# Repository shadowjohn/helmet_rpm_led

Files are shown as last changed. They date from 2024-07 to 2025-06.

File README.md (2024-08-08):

# helmet_rpm_led
(Arduino D1 mini) 這是一個引擎轉速在拉轉，安全帽上的燈條也在拉轉的故事...

假如我們可以抓到機車的引擎轉速，那就透過無線傳輸把轉速訊號傳到安全帽上顯示

<h3>作者：</h3>
	羽山秋人 (https://3wa.tw)
<br>
<h3>最初開發日期：</h3>
	2024-07-15 23:24
<br>
<h3>版權：</h3>
	MIT License
<br>	
<h3>所需材料：</h3>
<ul>
	<li>1. Arduino D1 mini x 2</li>
	<li>2. RGB Pixel 燈條 5V，間距的話建議 144 ，比較密，長度就自己覺得多長看得爽~</li>
    <li>3. PC817</li>
	<li>4. 基納 (5.1V 1/2w)</li>
	<li>5. 電阻 470Ω 1/2w</li>
	<li>6. 電阻 1KΩ 1/2w</li>
	<li>7. 電阻 1.2KΩ 1/2w</li>
	<li>8. 如果要裝上車，還需要 BUCK DC-to-DC MP1584</li>
    <li>9. 鋰電池 14500 3.7V 800mAh</li>
	<li>10. AA 3號電池 電池盒 單排或雙排</li>
	<li>11. 恥力要很夠</li>
</ul>
<br>
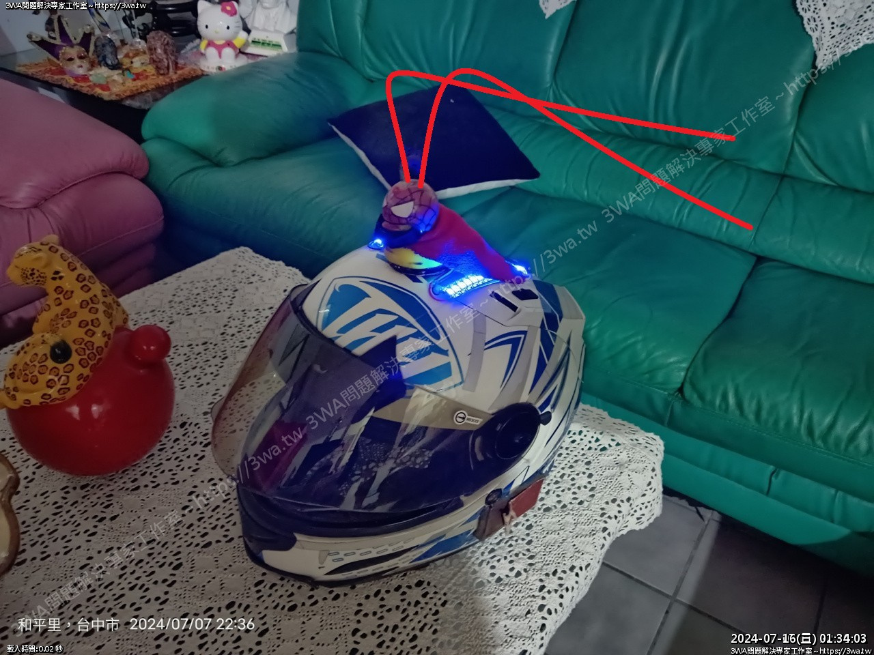
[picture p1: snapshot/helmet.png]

<center>假設那二條像嗄抓的尾巴是 LED 燈條，可以用來顯示車主瘋狂拉轉XD</center>

<br>
使用二塊有 Wifi 的 Arduino D1 mini 作為開發板

<h3>Server端(裝在安全帽上):</h3>
	啟動後會變成 Wifi AP ，等待 Client 端的轉速訊號，只要一收到轉速訊號，就變換燈條的顯示燈數與顏色
	傳輸過程使用 udp 封包
	此分享電路沒有畫出 12V -> 5V 的 Dc-to-DC Buck，可以考慮接個 MP1584 
	另外安全帽如果只用單串 18650 或 14500 ，可能需要用一組 Boost Converter 升壓到 5V 使用
	羽山有空再實驗

<br>
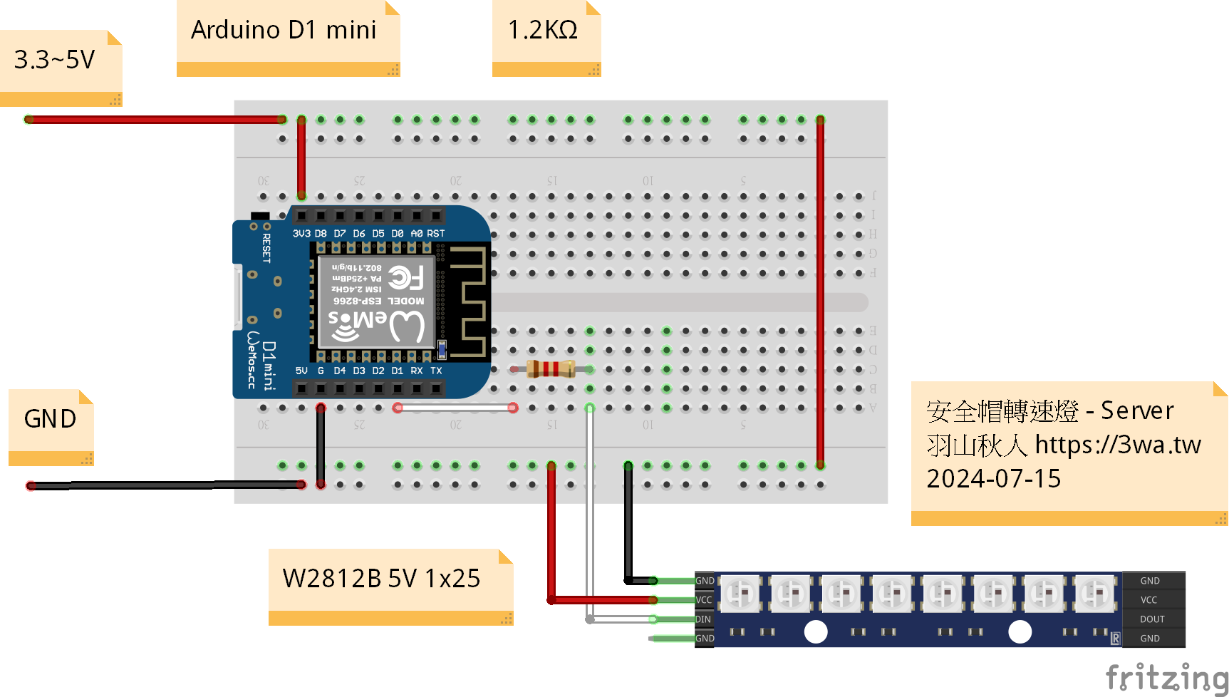
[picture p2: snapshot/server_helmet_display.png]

<center>(Server)安全帽上電路的接線方式</center>

<br>
<br>
<h3>Client端(裝在機車):</h3>
	啟動後會持續偵測引擎轉速，偵測的方式可以接碼表的轉速表訊號線，或是晶式高壓線圈輸入端的黑線或綠線，或是凸台的脈衝訊號線
<br>	
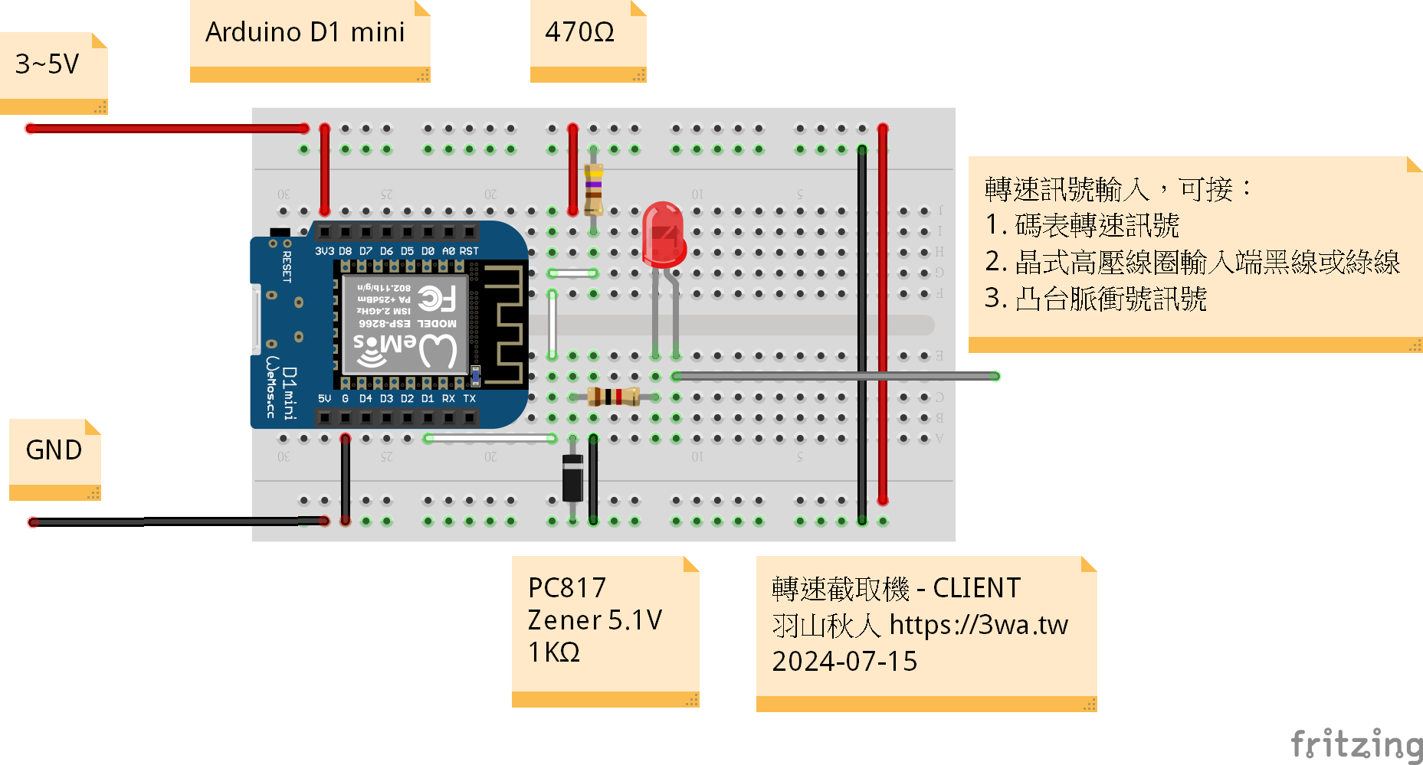
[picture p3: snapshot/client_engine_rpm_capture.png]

<center>(Client)轉速表訊號端的接線方式</center>

<br>
<video autoplay loop style="width:100%; height: auto; position:absolute; z-index: -1;">
  <source src="snapshot/helmet_rpm_led.mp4" type="video/mp4" />  
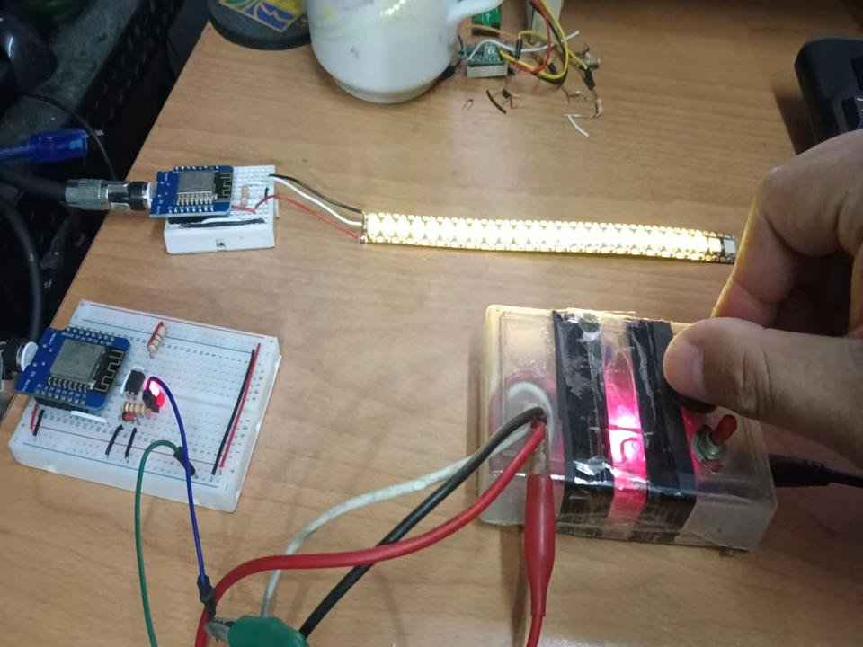
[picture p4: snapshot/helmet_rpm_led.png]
  
</video>
<br>
影片供參考：<a target="_blank" href="https://github.com/shadowjohn/helmet_rpm_led/blob/main/snapshot/helmet_rpm_led.mp4">實作影片</a>

<br><br>
<h3>心得：</h3>
	分享心得：https://3wa.tw/blog/blog.php?id=2091
<br>

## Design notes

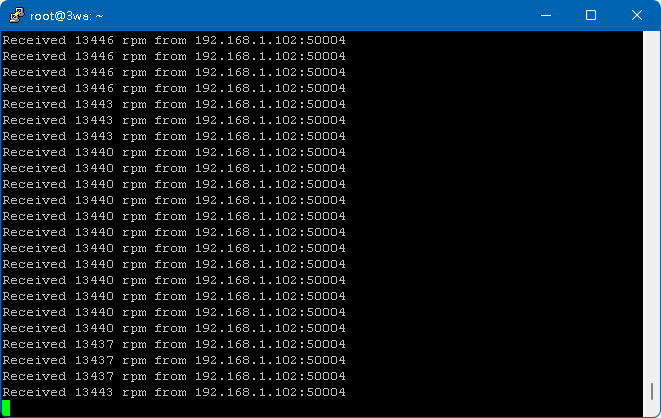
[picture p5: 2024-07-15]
snapshot/s2.png

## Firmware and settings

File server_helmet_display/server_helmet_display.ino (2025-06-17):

/*
 * 伺服端，啟動後會架一組 wifi server，連上的 client 會透過 udp 12345 丟轉速訊號來
 * Author: 羽山 (https://3wa.tw)
 * Author: @FB 田峻墉
 * Release Date: 2024-09-21
 * D1 接至 PC817，為轉速訊號接入端
 */
#include <Arduino.h>
#include <ESP8266WiFi.h>
#include <Adafruit_NeoPixel.h>
#include <WiFiUdp.h>

#define LED_PIN    D1 //接 Pixel LED
#define NUMPIXELS 25 // 25顆 LED
static Adafruit_NeoPixel strip(NUMPIXELS, LED_PIN, NEO_GRB + NEO_KHZ800);

// 收到的 udp 包
static char incomingPacket[255];
// 熱點名稱和密碼
const char* ssid = "3wa_helmet_server";
const char* password = "********";

// 指定熱點的 IP 地址、網關和子網掩碼
IPAddress local_ip(192,168,1,254);
IPAddress gateway(192,168,1,254); // 通常將網關設置為熱點的 IP 地址
IPAddress subnet(255,255,255,0);

// 創建一個 UDP 物件
WiFiUDP udp;
const int udpPort = 12345;


uint32_t blendColors(uint32_t color1, uint32_t color2, int blend) {
  uint8_t r1 = (color1 >> 16) & 0xFF;
  uint8_t g1 = (color1 >> 8) & 0xFF;
  uint8_t b1 = color1 & 0xFF;

  uint8_t r2 = (color2 >> 16) & 0xFF;
  uint8_t g2 = (color2 >> 8) & 0xFF;
  uint8_t b2 = color2 & 0xFF;

  uint8_t r = (r1 * (255 - blend) + r2 * blend) / 255;
  uint8_t g = (g1 * (255 - blend) + g2 * blend) / 255;
  uint8_t b = (b1 * (255 - blend) + b2 * blend) / 255;

  return strip.Color(r, g, b);
}
void displayOnLed(int show_rpm)
{
  // 將轉速顯示在NeoPixel LED
  int led_count = map(show_rpm, 0, 8000, 0, NUMPIXELS);
  led_count = (led_count<0)?0:led_count;
  led_count = (led_count>NUMPIXELS)?NUMPIXELS:led_count;
  for (int i = 0; i < NUMPIXELS; i++) {
    if (i < led_count) {
      uint32_t color1, color2;
      int range_start, range_end;

      if (show_rpm <= 4000) {
        color1 = strip.Color(0, 255, 0); // 綠色
        color2 = strip.Color(0, 255, 0); // 綠色
        range_start = 0;
        range_end = 4000;
      } else if (show_rpm <= 6000) {
        color1 = strip.Color(0, 255, 0); // 綠色
        color2 = strip.Color(255, 255, 0); // 黃色
        range_start = 4000;
        range_end = 6000;      
      } else if (show_rpm <= 8000) {
        color1 = strip.Color(255, 165, 0); // 橙色
        color2 = strip.Color(255, 0, 0); // 紅色
        range_start = 6000;
        range_end = 8000;      
      } else {
        color1 = strip.Color(255, 0, 0); // 紅色
        color2 = strip.Color(255, 255, 255); // 白色
        range_start = 8000;
        range_end = 10000;
      }

      int local_rpm = map(show_rpm, range_start, range_end, 0, 255);
      local_rpm = (local_rpm<0)?0: local_rpm;
      local_rpm = (local_rpm>255)?255: local_rpm;
      uint32_t color = blendColors(color1, color2, local_rpm);
     
      strip.setPixelColor(i, color);
    } else {
      strip.setPixelColor(i, 0); // 關閉LED
    }
  }
  if (show_rpm > 8000) 
  {
      if (random(0, 10) > 7) 
      {
        for (int i = 0; i < NUMPIXELS; i++) 
        {
            //color = strip.Color(0, 0, 0); // 關燈                   
            strip.setPixelColor(i, 0);
        }
     }
  }
  //strip.show();
}
void setup() {
  // 初始化串口通訊
  Serial.begin(115200);
  Serial.println();
  strip.begin();
  strip.show(); // Initialize all pixels to 'off'
  strip.setBrightness(20);
  
  // 配置熱點的 IP 地址、網關和子網掩碼
  WiFi.softAPConfig(local_ip, gateway, subnet);

  // 避免重連
  WiFi.setAutoConnect(false);
  WiFi.setAutoReconnect(false); 
  
  // 啟動隱藏的 WiFi 熱點，通道 11
  WiFi.softAP(ssid, password, 1, true);

  

  
  // 打印熱點的 IP 地址
  IPAddress myIP = WiFi.softAPIP();
  Serial.print("AP IP address: ");
  Serial.println(myIP);

  // 打印熱點啟動信息
  Serial.println("WiFi AP started");

  // 啟動 UDP
  udp.begin(udpPort);

  // 打印熱點啟動信息
  Serial.println("WiFi AP started");
}
bool isNumber(const char *str) {
  while (*str) {
    if (!isdigit(*str)) {
      return false;
    }
    str++;
  }
  return true;
}

unsigned long lastPacketTime = 0;
const unsigned long timeout = 1000; // 1秒的超時時間

unsigned long lastShowTime = 0;
const unsigned long lastShowTimeout = 10; // 10ms的超時時間

void loop() {  
  // 監聽 UDP 端口 12345
  int packetSize = udp.parsePacket();
  if (packetSize) {    
    int len = udp.read(incomingPacket, 255);
    if (len > 0) {
      incomingPacket[len] = 0; // Null-terminate the string
    }
    if (isNumber(incomingPacket)) {
        int rpm = atoi(incomingPacket);
        displayOnLed(rpm);
        lastPacketTime = millis(); // 更新最後收到資料的時間
    }      
  }
  // 檢查是否超時
  if (millis() - lastPacketTime > timeout) {
    displayOnLed(0); // 超時，顯示 0 RPM
    lastPacketTime = millis(); // 更新最後收到資料的時間
  }
  if (millis() - lastShowTime > lastShowTimeout) {
    strip.show();
    lastShowTime = millis(); // 更新顯示時間
  }
  yield(); // 用 yield() 來喂看門狗並讓出 CPU
}

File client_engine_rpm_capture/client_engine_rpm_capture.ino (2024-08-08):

/*
 * 轉速表，接高壓線圈輸入端綠線或黑線，或接轉速表訊號線，或凸台脈衝線圈訊號線
 * 這版接收到轉速表的訊號，會連上另一組 Arduino D1 mini 的 wifi
 * 成功連線後，會持續把轉速送出 udp 12345 port 至 server (192.168.1.254)
 * Author: 羽山 (https://3wa.tw)
 * Author: @FB 田峻墉
 * Release Date: 2024-07-15
 * D1 接至 PC817，為轉速訊號接入端
 */
#include <Arduino.h>
#include <ESP8266WiFi.h>
#include <WiFiUdp.h>
#include <Ticker.h>
WiFiEventHandler wifiConnectHandler;
WiFiEventHandler wifiDisconnectHandler;

#define WIFI_SSID "3wa_helmet_server"
#define WIFI_PASSWORD "********"

const char* udpAddress = "192.168.1.254"; // 伺服端(安全帽)的 IP 地址
const int udpPort = 12345; // 接收端的端口
WiFiUDP udp;

Ticker wifiReconnectTimer;
#define ToPin D6    //凸台、或轉速訊號線

volatile unsigned long C = micros(); //本次偵測到凸台的時間
volatile unsigned long C_old = 0; //上一次偵測到凸台的時間
volatile unsigned long rpm = 0; //換算後的轉速
volatile unsigned long RPM_DELAY = 0; //每一次轉速，凸台與凸台經過的時間
volatile unsigned int isShowCount = 0; //每次加一，每經過 100 次才更新一次七段，以免眼睛跟不上

/*
轉速   60 轉 =  每分鐘    60 轉，每秒  1    轉，1轉 = 1          秒 = 1000.000 ms = 1000000us
轉速   100 轉 = 每分鐘   100 轉，每秒  1.67 轉，1轉 = 0.598802   秒 =  598.802 ms =  598802us
轉速   200 轉 = 每分鐘   200 轉，每秒  3.3  轉，1轉 = 0.300003   秒 =  300.003 ms =  300003us
轉速   600 轉 = 每分鐘   600 轉，每秒  10   轉，1轉 = 0.1        秒 =  100.000 ms =  100000us
轉速  1500 轉 = 每分鐘  1500 轉，每秒  25   轉，1轉 = 0.04       秒 =   40.000 ms =   40000us
轉速  6000 轉 = 每分鐘  6000 轉，每秒  60   轉，1轉 = 0.01666... 秒 =   16.667 ms =   16667us
轉速 14000 轉 = 每分鐘 14000 轉，每秒 233.3 轉，1轉 = 0.0042863. 秒 =    4.286 ms =    4286us
轉速 14060 轉 = 每分鐘 14060 轉，每秒 240   轉，1轉 = 0.0041667. 秒 =    4.167 ms =    4167us
轉速 16000 轉 = 每分鐘 16000 轉，每秒 266.6 轉，1轉 = 0.0037500. 秒 =    3.750 ms =    3750us 
*/
void ICACHE_RAM_ATTR countup() {      
  //新版的 Nodemcu 在使用 ISR 中斷，Function 要加上 ICACHE_RAM_ATTR
  //偵測到凸台RISING，就會觸發此 function countup  
  C = micros(); //記錄當下的時間
  // (1/(16000/60) * 1000 * 1000 = 3750
  // (1/(17000/60) * 1000 * 1000 = 3529  
  // 不可能有超過 17000rpm 的狀況
  RPM_DELAY = C - C_old; //現在的時間減去上一次觸發的時間  
  if(RPM_DELAY < 3500) {
    //超過 17000rpm 了
    return;
  }
  if(RPM_DELAY > 598802) {
    //低於 100rpm
    C_old = C;
    rpm = 0;
    return;
  }    
  //其他轉速，計算得出轉速度
  rpm = 60000000UL / RPM_DELAY;
  //把上一次凸台的時間改成現在時間
  C_old = C;  
}
void connectToWifi() {
  Serial.println("Connecting to Wi-Fi...");
  WiFi.begin(WIFI_SSID, WIFI_PASSWORD);
}
void onWifiConnect(const WiFiEventStationModeGotIP& event) {
  Serial.println("Connected to Wi-Fi.");
  Serial.print("IP address: ");
  Serial.println(event.ip.toString());  // 打印 IP 地址 
}
void onWifiDisconnect(const WiFiEventStationModeDisconnected& event) {
  Serial.println("Disconnected from Wi-Fi.");  
  wifiReconnectTimer.once(2, connectToWifi);
}
void setup() {  
  Serial.begin(115200); //注意包率設很高，要在監視器看的話要改一下
  Serial.println("Counting...");
  //宣告觸發腳位為 INPUT_PULLUP
  pinMode(ToPin, INPUT_PULLUP);    
  //註冊中斷觸發
  attachInterrupt(digitalPinToInterrupt(ToPin), countup, RISING); //RISING

  wifiConnectHandler = WiFi.onStationModeGotIP(onWifiConnect);
  wifiDisconnectHandler = WiFi.onStationModeDisconnected(onWifiDisconnect);
  connectToWifi(); 
}

void loop() {
  //七段顯示器不能一直刷數字，不然人類的眼睛會追不上
  //isShowCount 每一次都加1，計數100次才改變一次七段顯示器的內容，顯示完就歸零
  //如果覺得眼睛還是追不上，可以把 100 調大一些，如 150、200
  isShowCount++;  
  if (isShowCount > 100)
  {    
    isShowCount = 0;   
    if(micros() - C_old > 598802) {
      //2021-09-21 針對訊號源消失的處理
      //低於 100rpm      
      rpm = 0;      
    }    
    //七段最多顯示到 9999，所以超過 10000 都變 9999
    //rpm = (rpm>=10000)?9999:rpm;  
    //顯示在七段上
    //預設為 2 行程使用
    //如果為 4 行程引擎，要 x 2 倍
    //rpm *= 2;
    displayOnLed(rpm);   
  }  
}
void displayOnLed(int show_rpm)
{
  // 把轉速訊號傳去 server 顯示
  char buffer[10];
  itoa(show_rpm, buffer, 10); // 將轉速數據轉換為字串

  if(WiFi.status() == WL_CONNECTED){
    udp.beginPacket(udpAddress, udpPort);
    udp.write(buffer);
    udp.endPacket();
    Serial.println(show_rpm);        
  }
}

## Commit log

2024-07-15 初次簽入
2024-07-16 更新電路圖
    [client_engine_rpm_capture.fzz, server_helmet_display.fzz]
2024-07-16 更新 README.md
2024-08-08 修正當機問題
2024-08-09 更新接線圖
    [client_engine_rpm_capture.fzz, server_helmet_display.fzz]
2025-06-17 防crash的部分
